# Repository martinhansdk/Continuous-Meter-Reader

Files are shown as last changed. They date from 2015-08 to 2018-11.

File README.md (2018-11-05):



# Continuous Meter Reader

A little gadget that sits on your water or electricity meter and
monitors it continuously.  The collected reading are presented on a
mobile web page so that you can practice saving ressources by
answering questions like "How much water do I use when I take a
shower?".

Currently Sensus water meters are supported. They look like this:

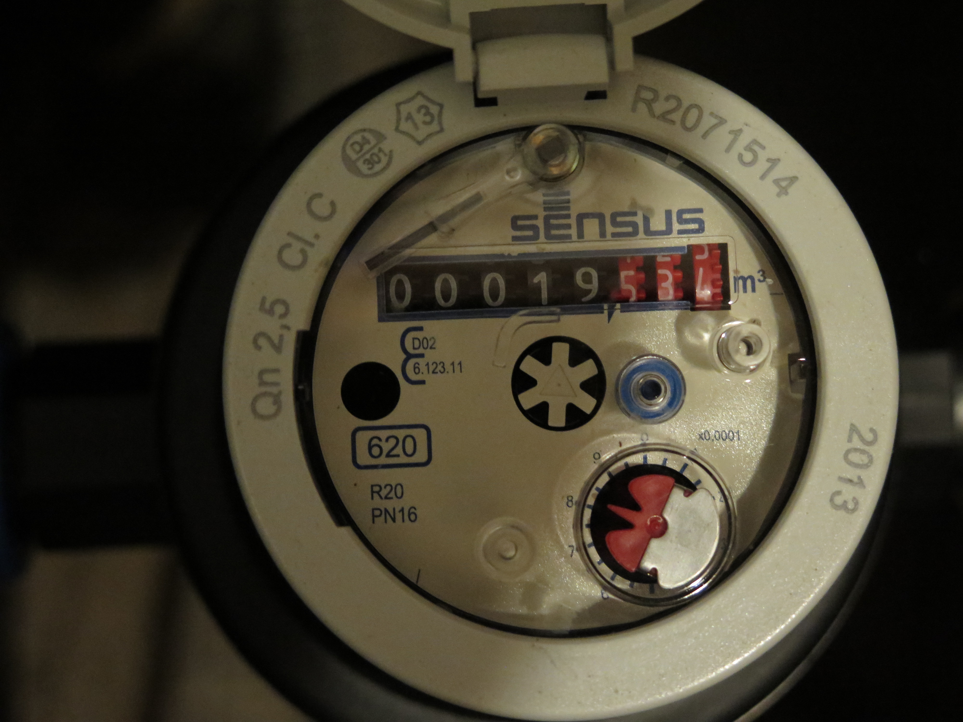
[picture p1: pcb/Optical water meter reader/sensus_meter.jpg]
Sensus water meter


I have designed two versions of a PCB which fits on top of the water
meter which uses [GP2S700HCP reflective
photointerrupter](http://www.sharp-world.com/products/device/lineup/data/pdf/datasheet/gp2s700hcp_e.pdf)
sensors to read the turning of the half shiny half red disc. The disc
makes one turn per liter. The PCB has six optical sensors, so it can
sense quantities around 1/12 of a liter. The reflective part of the
disc is not exactly a half circle, so the exact 12 quantities measured
are different from each other. An automatic calibration method is
provided which determines how much each quantity is. You can print a
[PDF rendering of the PCB layout](pcb/Optical%20water%20meter%20reader/optical%20meter%20reader%20board.pdf), make 5mm holes for the
steering pins plus a small hole for the middle of the sensor circle in
your printout and see if it will fit on your meter. When attached to
your meter the small hole should be right above the center of the
disc.

Photo of the PCB

* The top row shows the version of the PCB designed to run on two 1.5V batteries and transmit the readings wirelessly.
  * [Eagle schematics](pcb/Optical%20water%20meter%20reader/optical%20meter%20reader%20v3.sch) / [PDF schematics](pcb/Optical%20water%20meter%20reader/optical%20meter%20reader%20v3%20battery%20assembly.pdf)
  * [Eagle board file](pcb/Optical%20water%20meter%20reader/optical%20meter%20reader%20v3.brd)
  * [Gerber files](pcb/Optical%20water%20meter%20reader/optical%20meter%20reader%20v3%20-%20gerber.zip)
  * [Bill of materials](pcb/Optical%20water%20meter%20reader/optical%20meter%20reader%20v3%20battery%20assembly%20BOM.txt)
  * [Firmware](src/Continuous-Meter-Reader/Continuous-Meter-Reader.ino)
* The bottom row shows the version of the PCB designed to be connected directly to a PC using a USB cable. In the configuration shown here it operates as the radio receiver that receives the readings transmitted from other units.
  * [Eagle schematics](pcb/Optical%20water%20meter%20reader/optical%20meter%20reader.sch) / [PDF schematics](pcb/Optical%20water%20meter%20reader/optical%20meter%20reader.pdf)
  * [Eagle board file](pcb/Optical%20water%20meter%20reader/optical%20meter%20reader.brd)
  * [Gerber files](pcb/Optical%20water%20meter%20reader/optical%20meter%20reader%20gerber.zip)
  * [Firmware](src/RadioStation/RadioStation.ino)

The ambition is that the same or a similar PCB will be able to read
the turning weel on an old style electricity meter. The PCB was
designed in [Eagle pcb](http://www.cadsoftusa.com/).

The USB version uses an [Arduino
Nano](https://www.arduino.cc/en/Main/ArduinoBoardNano) as the CPU
module and [NRF24L01+ Wireless Transceiver
Module](http://www.icstation.com/1pcs-nrf24l0124ghz-wireless-transceiver-module-arduino-p-1388.html)
for wireless connectivity. The battery powered module has the
microcontroller directly on the PCB and uses the same wireless transceiver.

The server application runs on a PC written in
[Go](https://golang.org/) and stores the measurements in a
[PostgreSQL](http://www.postgresql.org) database. The server application
exposes a REST API, a [socket.io](http://socket.io/) service for real
time updates and also serves a web application written in
[React](http://facebook.github.io/react/).

The communication protocol between the embedded code and the server is
based on [Google's protocol
buffers](https://developers.google.com/protocol-buffers/) with the
Arduino implementation generated by
[Nanopb](http://koti.kapsi.fi/jpa/nanopb/). The protocol definition
file is [MeterReader.proto](MeterReader.proto).

## Software build instructions

All build instructions assume Ubuntu 15.04 or later.

### Install prerequisites

    sudo apt-get install make clang protobuf-compiler arduino postgresql-9.4 git
    wget https://godeb.s3.amazonaws.com/godeb-amd64.tar.gz
    tar xzf godeb-amd64.tar.gz
    ./godeb install

### Getting the code

The project uses git submodules, so you have to use a recursive clone to get everything:

    git clone --recursive https://github.com/martinhansdk/Continuous-Meter-Reader

### Uploading the embedded code to the MCU on the battery powered meter reader node

Using an AVR ISP programmer (for instance an Arduino with the
ArduinoISP sketch loaded), attach it to the ISP header on the meter
reader board. In the Arduino IDE select the appropriate programmer
type.  Choose the board type to be "Arduino Pro or Pro Mini (3.3V, 8
MHz) w/ ATmega328". Then run "Tools > Burn bootloader".

Once this has completed correctly, the brown out detection must be
cleared in the AVR in order to allow operating the AVR at 2.5V. Do
this by running:

    avrdude -patmega328p -cstk500v1 -P /dev/ttyUSB? -b19200 -U efuse:w:0xff:m

Now disconnect the ISP and connect a 3.3V FTDI USB to serial adapter to
JP2. The run

    cd src/Continuous-Meter-Reader
    make upload

### Uploading the embedded code to the Arduino on the receiver station
    
Attach the Arduino for the server receiver station and run

    cd src/RadioStation
    make upload
    
### Building the server and node configuration tool

    cd go
    export GOPATH=$PWD
    go get -d
    go build MeterServer.go 
    go build ConfigNode.go 
    go build SampleSender.go 

### Setup the PostgreSQL database

Drop step 1 if you already have a database running

1. change postgres default password:
   su - postgres
   psql
   \password postgres
   <enter new password>
2. Create the 'meter' user:
   CREATE USER meter;
3. Set user password:
   \password meter;
   <use password: meter2>
3. Create the database:
   CREATE DATABASE meter;
4. Grant priviledges to meter on database:
   GRANT ALL PRIVILEGES ON DATABASE meter TO meter;
5. Grant priviledges to meter on the database tables:
   GRANT ALL PRIVILEGES ON TABLE meters TO meter;
   GRANT ALL PRIVILEGES ON TABLE measurements TO meter;
6. Create the database fields by executing the commands in database.sql
7. Insert the first meter into the meter table:
   INSERT INTO meters(
               id, name, unit, current_series, last_count, scale)
       VALUES (1, 'Mock meter', "L", "0", "0", 1e-3),
              (10,  "Water", "L", "0", "0", 1e-3);
   
### Configuring the Arduino for a meter

Each node has an id which is an integer between 1 and 127. We need to
set this id and also choose the wireless or serial (USB)
protocol. Configuration can only happen over USB.

To configure an Arduino that is attached to /dev/ttyUSB0 run something like the following:

    go/ConfigNode -serial=/dev/ttyUSB0 -wirelessproto -id=10 -uncalibrate

### Calibrating a meter sensor

The calibration procedure is as follows:

1. Attach the PCB to the water meter
2. Connect the Arduino to the PC using a USB cable
3. Turn on a tap so that a constant flow is running. Make sure this is the only place water is consumed in the house while the calibration is running
4. Run the command `go/ConfigNode -serial=/dev/ttyUSB0 -calibrate`
5. The command will exit when calibration is complete

### Running the Server

Once the database is set up, and the MeterServer built, it can be run:

   cd go
   ./MeterServer

Contact the server using http://localhost:2111/static

## Running the mock meter (offline mode)

Running tests with out having to flush a lot of water makes sense, so use the

   cd go
   ./SampleSender

for this purpose.

If everything is ok, the example output should look something like this:

    2015/11/10 22:25:00 Waiting for current settings
    2015/11/10 22:25:00 Connection established
    2015/11/10 22:25:00 Waiting for data
    2015/11/10 22:25:02 len= 14
    2015/11/10 22:25:02 n=14
    2015/11/10 22:25:02 NOTE : Received 'Rebooted'
    2015/11/10 22:25:02 Waiting for data
    2015/11/10 22:25:02 len= 24
    2015/11/10 22:25:02 n=24
    2015/11/10 22:25:02 Waiting for data
    2015/11/10 22:25:02 Got current settings
    {"meterId":2,"seriesId":73,"communicationChannel":1,"risingEdgeAmounts":[0,1,2,3,4,5],"fallingEdgeAmounts":[0,1,2,3,4,5]}
    2015/11/10 22:25:02 id=4294967295
    2015/11/10 22:25:57 len= 27
    2015/11/10 22:25:57 n=27
    2015/11/10 22:25:57 Waiting for data
    {"meterId":2,"seriesId":73,"communicationChannel":1,"risingEdgeAmounts":[127,93,117,149,169,153],"fallingEdgeAmounts":[33,15,17,38,41,48]}

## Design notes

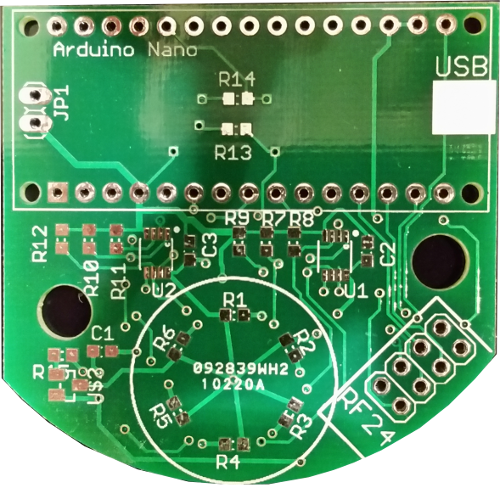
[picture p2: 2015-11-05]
pcb/Optical water meter reader/optical meter reader pcb photo.png

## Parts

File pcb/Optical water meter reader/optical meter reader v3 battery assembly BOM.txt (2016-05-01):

Partlist exported from C:/Users/Hans/Documents/eagle/Optical water meter reader/optical meter reader v3.sch at 2016-04-21 11:47 AM

Part  Value          Device                    Package       Description                                                                                                                                                                                                        
C1    100n           C-USC0603                 C0603         CAPACITOR, American symbol                                                                                                                                                                                         
C2    100n           C-USC0603                 C0603         CAPACITOR, American symbol                                                                                                                                                                                         
C3    100n           C-USC0603                 C0603         CAPACITOR, American symbol                                                                                                                                                                                         
C4    100n           C-USC0603                 C0603         CAPACITOR, American symbol                                                                                                                                                                                         
C5    100n           C-USC0603                 C0603         CAPACITOR, American symbol                                                                                                                                                                                         
C6    100n           C-USC0603                 C0603         CAPACITOR, American symbol                                                                                                                                                                                         
C7    100n           C-USC0603                 C0603         CAPACITOR, American symbol                                                                                                                                                                                         
C8    10u            C-EUC0603                 C0603         CAPACITOR, European symbol                                                                                                                                                                                         
C9    10u            C-USC0603                 C0603         CAPACITOR, American symbol                                                                                                                                                                                         
C10   10u            C-USC0603                 C0603         CAPACITOR, American symbol                                                                                                                                                                                         
JP2   FTDI Basic     ARDUINO_SERIAL_PROGRAMPTH 1X06                                                                                                                                                                                                                             
JP3   RF24           PINHD-2X4                 2X04          PIN HEADER                                                                                                                                                                                                         
JP5   LUM1613-14     LUM1613-14                1613-14       Lumberg 1613 12 DC power connector                                                                                                                                                                                 
JP6   2X4SMD         2X4SMD                    2X4_SMD                                                                                                                                                                                                                          
LED1  Green          LED                       0603-LED-ALT1 LEDs                                                                                                                                                                                                               
LOGO1 OSHW-LOGOL     OSHW-LOGOL                OSHW-LOGO-L   Open Source Hardware Logo This logo indicates the piece of hardware it is found on incorporates a OSHW license and/or adheres to the definition of open source hardware found here: http://freedomdefined.org/OSHW 
LOGO2 OSHW-LOGOL     OSHW-LOGOL                OSHW-LOGO-L   Open Source Hardware Logo This logo indicates the piece of hardware it is found on incorporates a OSHW license and/or adheres to the definition of open source hardware found here: http://freedomdefined.org/OSHW 
Q1    8MHz           CSTCE                     CSTCE         Murata CSTCE                                                                                                                                                                                                       
R1    10K            R-US_R0603                R0603         RESISTOR, American symbol                                                                                                                                                                                          
R2    1k             R-US_R0603                R0603         RESISTOR, American symbol                                                                                                                                                                                          
R3    1k             R-US_R0603                R0603         RESISTOR, American symbol                                                                                                                                                                                          
R4    750            R-US_R0603                R0603         RESISTOR, American symbol                                                                                                                                                                                          
R5    1k             R-US_R0603                R0603         RESISTOR, American symbol                                                                                                                                                                                          
R8    1k             R-US_R0603                R0603         RESISTOR, American symbol                                                                                                                                                                                          
R12   3k             R-US_R0603                R0603         RESISTOR, American symbol                                                                                                                                                                                          
R13   3k             R-US_R0603                R0603         RESISTOR, American symbol                                                                                                                                                                                          
R14   3k             R-US_R0603                R0603         RESISTOR, American symbol                                                                                                                                                                                          
R15   3k             R-US_R0603                R0603         RESISTOR, American symbol                                                                                                                                                                                          
R16   3k             R-US_R0603                R0603         RESISTOR, American symbol                                                                                                                                                                                          
R17   3k             R-US_R0603                R0603         RESISTOR, American symbol                                                                                                                                                                                          
R19   82             R-US_R0603                R0603         RESISTOR, American symbol                                                                                                                                                                                          
R20   82             R-US_R0603                R0603         RESISTOR, American symbol                                                                                                                                                                                          
R21   82             R-US_R0603                R0603         RESISTOR, American symbol                                                                                                                                                                                          
R22   82             R-US_R0603                R0603         RESISTOR, American symbol                                                                                                                                                                                          
R23   82             R-US_R0603                R0603         RESISTOR, American symbol                                                                                                                                                                                          
R24   82             R-US_R0603                R0603         RESISTOR, American symbol                                                                                                                                                                                          
R26   1M             R-US_R0603                R0603         RESISTOR, American symbol                                                                                                                                                                                          
R27   2M             R-US_R0603                R0603         RESISTOR, American symbol                                                                                                                                                                                          
R32   0              R-US_R0603                R0603         RESISTOR, American symbol                                                                                                                                                                                          
S0    GP2S700HCP     GP2S700HCP                SMD                                                                                                                                                                                                                              
S1    GP2S700HCP     GP2S700HCP                SMD                                                                                                                                                                                                                              
S2    GP2S700HCP     GP2S700HCP                SMD                                                                                                                                                                                                                              
S3    GP2S700HCP     GP2S700HCP                SMD                                                                                                                                                                                                                              
S4    GP2S700HCP     GP2S700HCP                SMD                                                                                                                                                                                                                              
S5    GP2S700HCP     GP2S700HCP                SMD                                                                                                                                                                                                                              
T1    IRML6401       IRML6401                  SOT23                                                                                                                                                                                                                            
T2    IRML6401       IRML6401                  SOT23                                                                                                                                                                                                                            
U1    LM8364         LM8364                    SOT23-DBV     LM8364 Micropower Undervoltage Sensing Circuits                                                                                                                                                                    
U2    ATMEGA328P     ATMEGA168                 TQFP32-08                                                                                                                                                                                                                        
U3    SN74LVC3G17DCT SN743G17DCT               SSOP08                                                                                                                                                                                                                           
U4    SN74LVC3G17DCT SN743G17DCT               SSOP08                                                                                                                                                                                                                           
U5    MCP1700 2V5    MCP1700                   SOT23

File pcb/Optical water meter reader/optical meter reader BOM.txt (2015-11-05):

Partlist exported from C:/Users/Hans/Documents/eagle/Optical water meter reader/optical meter reader.sch at 28-Aug-15 11:16 PM

Part Value       Device      Package Description                
C1   2.2u        C-EUC0603   C0603   CAPACITOR, European symbol 
C2   100n        C-USC0603   C0603   CAPACITOR, American symbol 
C3   100n        C-USC0603   C0603   CAPACITOR, American symbol 
JP1              PINHD-1X2   1X02    PIN HEADER                 
JP2  RF24        PINHD-2X4   2X04    PIN HEADER                 
R1   220         R-US_R0603  R0603   RESISTOR, American symbol  
R2   220         R-US_R0603  R0603   RESISTOR, American symbol  
R3   220         R-US_R0603  R0603   RESISTOR, American symbol  
R4   220         R-US_R0603  R0603   RESISTOR, American symbol  
R5   220         R-US_R0603  R0603   RESISTOR, American symbol  
R6   220         R-US_R0603  R0603   RESISTOR, American symbol  
R7   10k         R-US_R0603  R0603   RESISTOR, American symbol  
R8   10k         R-US_R0603  R0603   RESISTOR, American symbol  
R9   10k         R-US_R0603  R0603   RESISTOR, American symbol  
R10  10k         R-US_R0603  R0603   RESISTOR, American symbol  
R11  10k         R-US_R0603  R0603   RESISTOR, American symbol  
R12  10k         R-US_R0603  R0603   RESISTOR, American symbol  
R13  220         R-US_R0603  R0603   RESISTOR, American symbol  
R14  10k         R-US_R0603  R0603   RESISTOR, American symbol  
R15  1k          R-US_R0603  R0603   RESISTOR, American symbol  
S0   GP2S700HCP  GP2S700HCP  SMD                                
S1   GP2S700HCP  GP2S700HCP  SMD                                
S2   GP2S700HCP  GP2S700HCP  SMD                                
S3   GP2S700HCP  GP2S700HCP  SMD                                
S4   GP2S700HCP  GP2S700HCP  SMD                                
S5   GP2S700HCP  GP2S700HCP  SMD                                
S6   GP2S700HCP  GP2S700HCP  SMD                                
U$1  ARDUINONANO ARDUINONANO PDIP-32                            
U$2  IRLML6401   IRLML6401   SOT23                              
U1   SN743G17DCT SN743G17DCT SSOP08                             
U2   SN743G17DCT SN743G17DCT SSOP08

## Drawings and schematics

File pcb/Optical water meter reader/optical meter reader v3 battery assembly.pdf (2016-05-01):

# R18 R¹¹

3

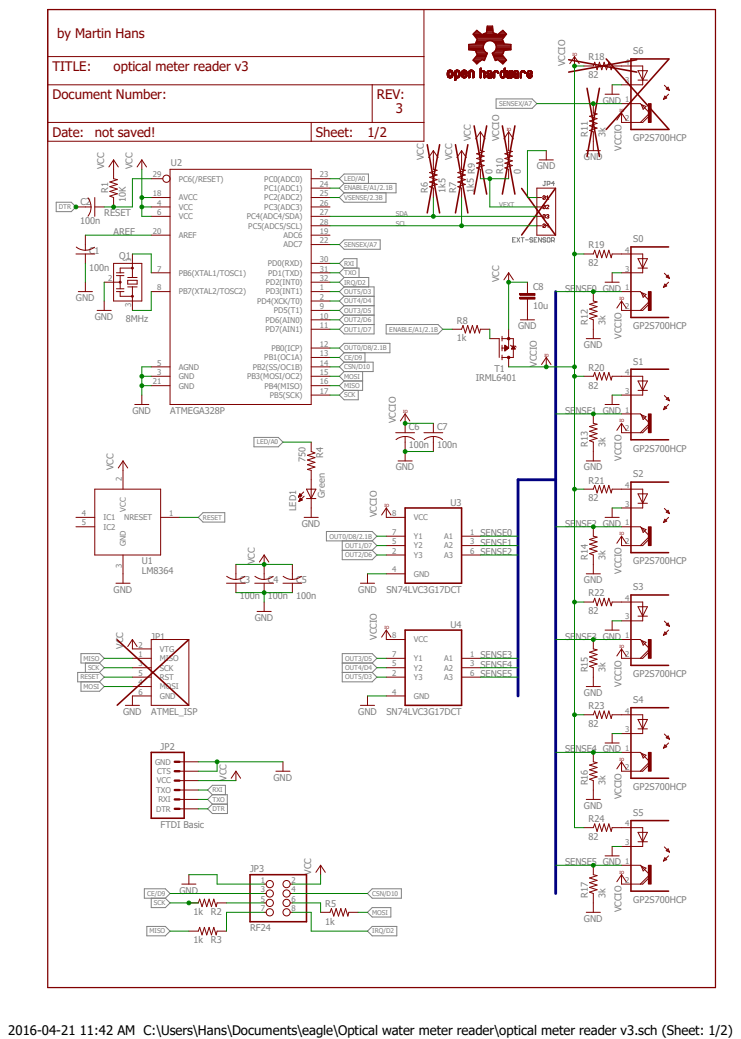
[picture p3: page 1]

AREF | | VCC 6
AREF 20 | SCL

2016-04-21 11:42 AM C:\Users\Hans\Documents\eagle\Optical water meter reader\optical meter reader v3.sch (Sheet: 1/2)

3

## by Martin Hans

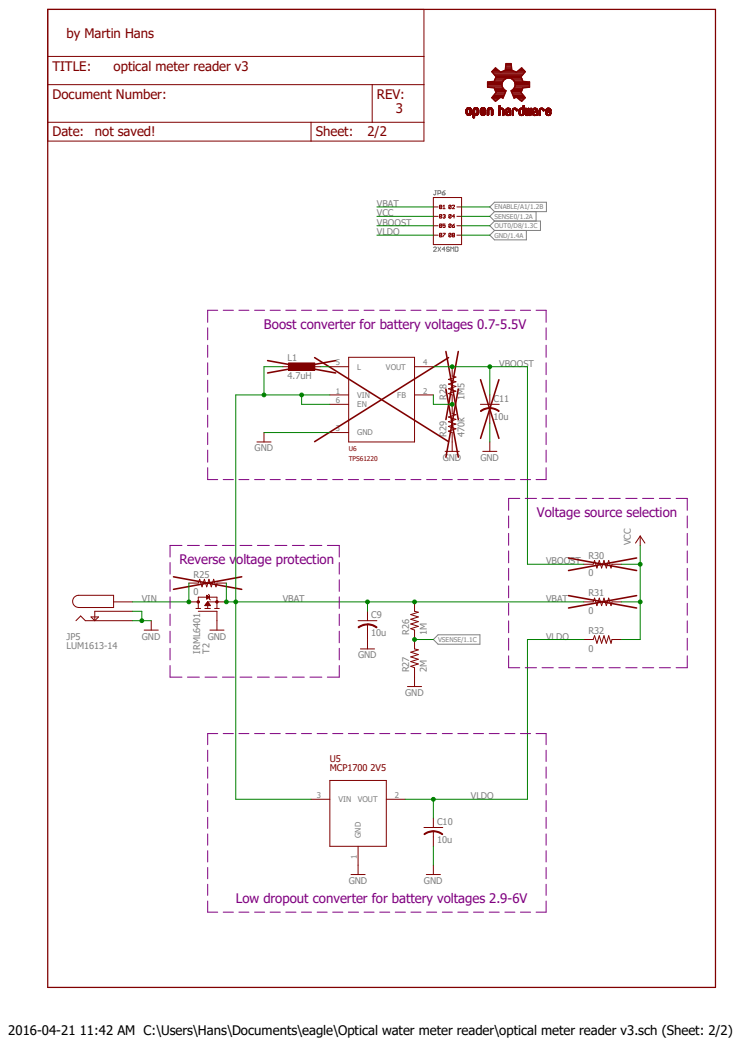
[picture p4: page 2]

Low dropout converter for battery voltages 2.9-6V

2016-04-21 11:42 AM C:\Users\Hans\Documents\eagle\Optical water meter reader\optical meter reader v3.sch (Sheet: 2/2)

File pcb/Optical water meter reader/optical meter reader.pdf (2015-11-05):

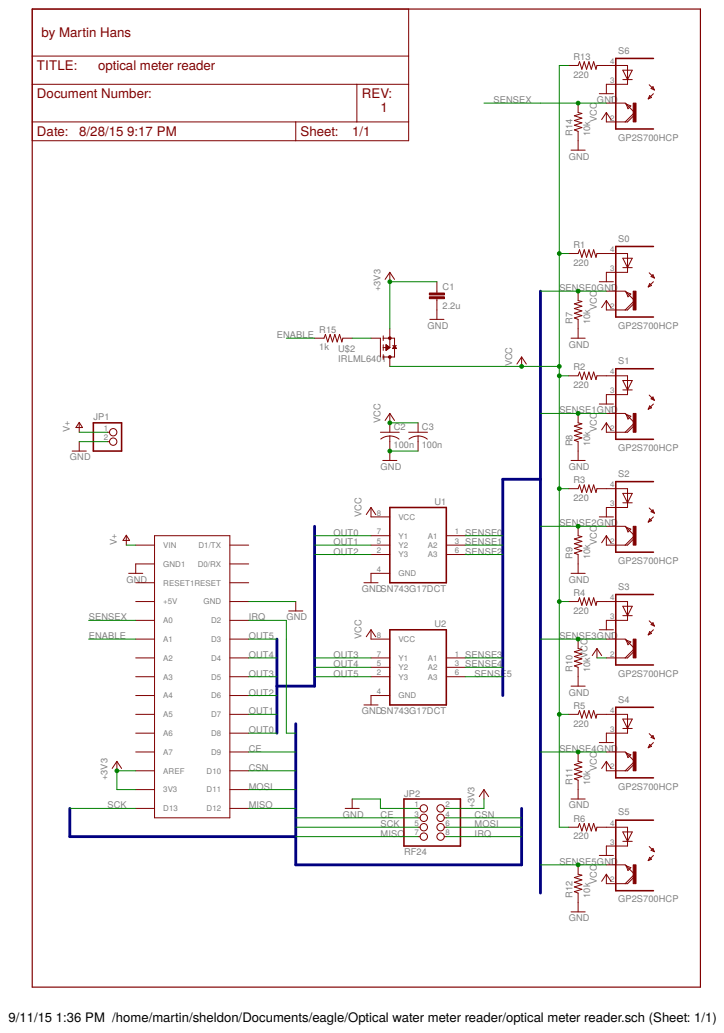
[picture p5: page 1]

D1/TX D0/RX RESET GND

9/11/15 1:36 PM /home/martin/sheldon/Documents/eagle/Optical water meter reader/optical meter reader.sch (Sheet: 1/1)

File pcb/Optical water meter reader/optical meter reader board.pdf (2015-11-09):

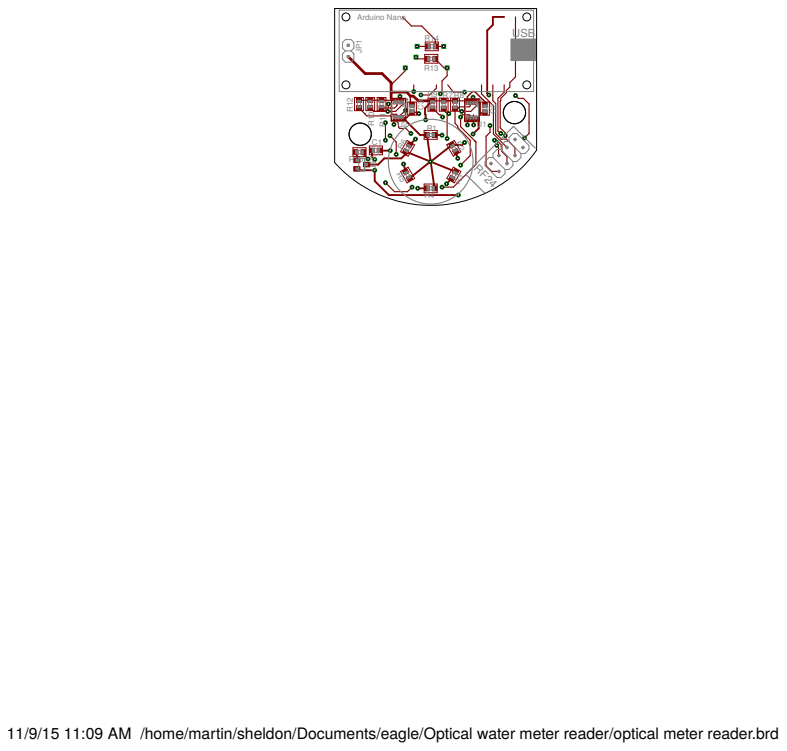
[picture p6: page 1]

11/9/15 11:09 AM /home/martin/sheldon/Documents/eagle/Optical water meter reader/optical meter reader.brd

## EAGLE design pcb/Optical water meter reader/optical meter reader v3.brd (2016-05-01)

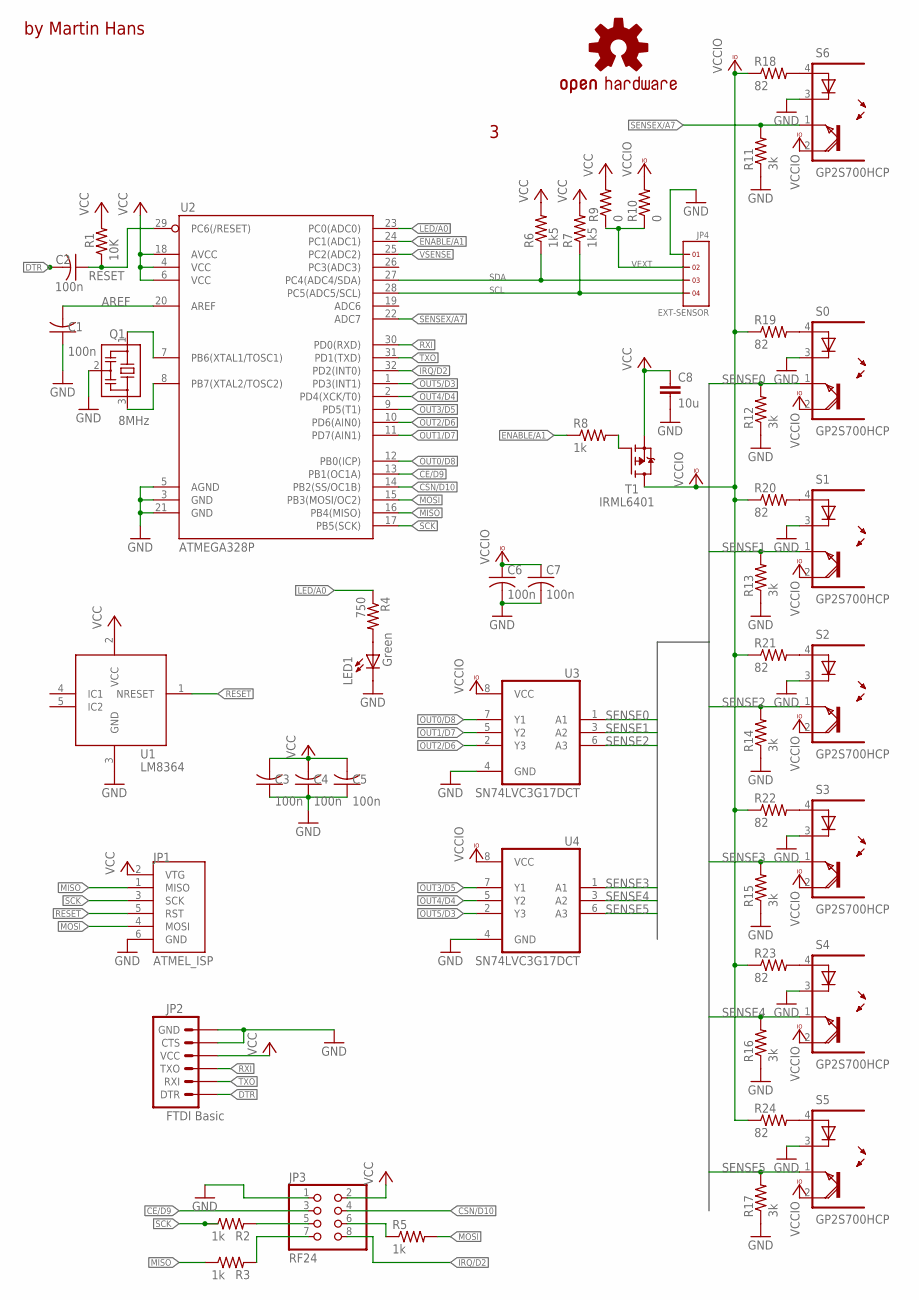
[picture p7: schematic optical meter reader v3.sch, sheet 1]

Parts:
C1, C2, C3, C4, C5, C6, C7: 100n; C0603
C8: 10u; C0603
JP1: ATMEL_ISP; 2X03
JP2: FTDI Basic; 1X06
JP3: RF24; 2X04
JP4: EXT-SENSOR; 1X4
LED1: Green; 0603-LED-ALT1
LOGO1: OSHW-LOGOL; OSHW-LOGO-L
Q1: 8MHz; CSTCE
R1: 10K; R0603
R2, R3, R5, R8: 1k; R0603
R4: 750; R0603
R6, R7: 1k5; R0603
R9, R10: 0; R0603
R11, R12, R13, R14, R15, R16, R17: 3k; R0603
R18, R19, R20, R21, R22, R23, R24: 82; R0603
S0, S1, S2, S3, S4, S5, S6: GP2S700HCP; SMD
T1: IRML6401; SOT23
U1: LM8364; SOT23-DBV
U2: ATMEGA328P; TQFP32-08
U3, U4: SN74LVC3G17DCT; SSOP08

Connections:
AREF: C1.2, U2.20 (AREF)
CE/D9: JP3.3, U2.13 (PB1(OC1A))
CSN/D10: JP3.4, U2.14 (PB2(SS/OC1B))
DTR: C2.2, JP2.1 (DTR)
ENABLE/A1: R8.1, U2.24 (PC1(ADC1)); also elsewhere on the board
GND: C1.1, C3.1, C4.1, C5.1, C6.2, C7.2, C8.2, JP1.6 (GND), JP2.5 (CTS), JP2.6 (GND), JP3.1, JP4.1, LED1.C, Q1.2, R11.1, R12.1, R13.1, R14.1, R15.1, R16.1, R17.1, S0.3 (C), S1.3 (C), S2.3 (C), S3.3 (C), S4.3 (C), S5.3 (C), S6.3 (C), U1.3 (GND), U2.3 (GND), U2.5 (AGND), U2.21 (GND), U3.4 (GND), U4.4 (GND); also elsewhere on the board
IRQ/D2: JP3.8, U2.32 (PD2(INT0))
LED/A0: R4.1, U2.23 (PC0(ADC0))
MISO: JP1.1 (MISO), R3.1, U2.16 (PB4(MISO))
MOSI: JP1.4 (MOSI), R5.2, U2.15 (PB3(MOSI/OC2))
unnamed: R19.2, S0.4 (A)
unnamed: R20.2, S1.4 (A)
unnamed: R21.2, S2.4 (A)
unnamed: R22.2, S3.4 (A)
unnamed: R23.2, S4.4 (A)
unnamed: R18.2, S6.4 (A)
unnamed: R8.2, T1.1 (G)
unnamed: R24.2, S5.4 (A)
unnamed: LED1.A, R4.2
unnamed: Q1.3, U2.8 (PB7(XTAL2/TOSC2))
unnamed: Q1.1, U2.7 (PB6(XTAL1/TOSC1))
unnamed: JP3.6, R5.1
unnamed: JP3.7, R3.2
unnamed: JP3.5, R2.2
OUT0/D8: U2.12 (PB0(ICP)), U3.7 (Y1); also elsewhere on the board
OUT1/D7: U2.11 (PD7(AIN1)), U3.5 (Y2)
OUT2/D6: U2.10 (PD6(AIN0)), U3.2 (Y3)
OUT3/D5: U2.9 (PD5(T1)), U4.7 (Y1)
OUT4/D4: U2.2 (PD4(XCK/T0)), U4.5 (Y2)
OUT5/D3: U2.1 (PD3(INT1)), U4.2 (Y3)
RESET: C2.1, JP1.5 (RST), R1.1, U1.1 (NRESET), U2.29 (PC6(/RESET))
RXI: JP2.3 (TXO), U2.30 (PD0(RXD))
SCK: JP1.3 (SCK), R2.1, U2.17 (PB5(SCK))
SCL: JP4.4, R7.1, U2.28 (PC5(ADC5/SCL))
SDA: JP4.3, R6.1, U2.27 (PC4(ADC4/SDA))
SENSE0: R12.2, S0.1 (EMI), U3.1 (A1); also elsewhere on the board
SENSE1: R13.2, S1.1 (EMI), U3.3 (A2)
SENSE2: R14.2, S2.1 (EMI), U3.6 (A3)
SENSE3: R15.2, S3.1 (EMI), U4.1 (A1)
SENSE4: R16.2, S4.1 (EMI), U4.3 (A2)
SENSE5: R17.2, S5.1 (EMI), U4.6 (A3)
SENSEX/A7: R11.2, S6.1 (EMI), U2.22 (ADC7)
TXO: JP2.2 (RXI), U2.31 (PD1(TXD))
VCC: C3.2, C4.2, C5.2, C8.1, JP1.2 (VTG), JP2.4 (VCC), JP3.2, R1.2, R6.2, R7.2, R9.2, T1.2 (S), U1.2 (VCC), U2.4 (VCC), U2.6 (VCC), U2.18 (AVCC); also elsewhere on the board
VCCIO: C6.1, C7.1, R10.2, R18.1, R19.1, R20.1, R21.1, R22.1, R23.1, R24.1, S0.2 (COL), S1.2 (COL), S2.2 (COL), S3.2 (COL), S4.2 (COL), S5.2 (COL), S6.2 (COL), T1.3 (D), U3.8 (VCC), U4.8 (VCC)
VEXT: JP4.2, R9.1, R10.1
VSENSE: U2.25 (PC2(ADC2)); also elsewhere on the board

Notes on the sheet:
by Martin Hans

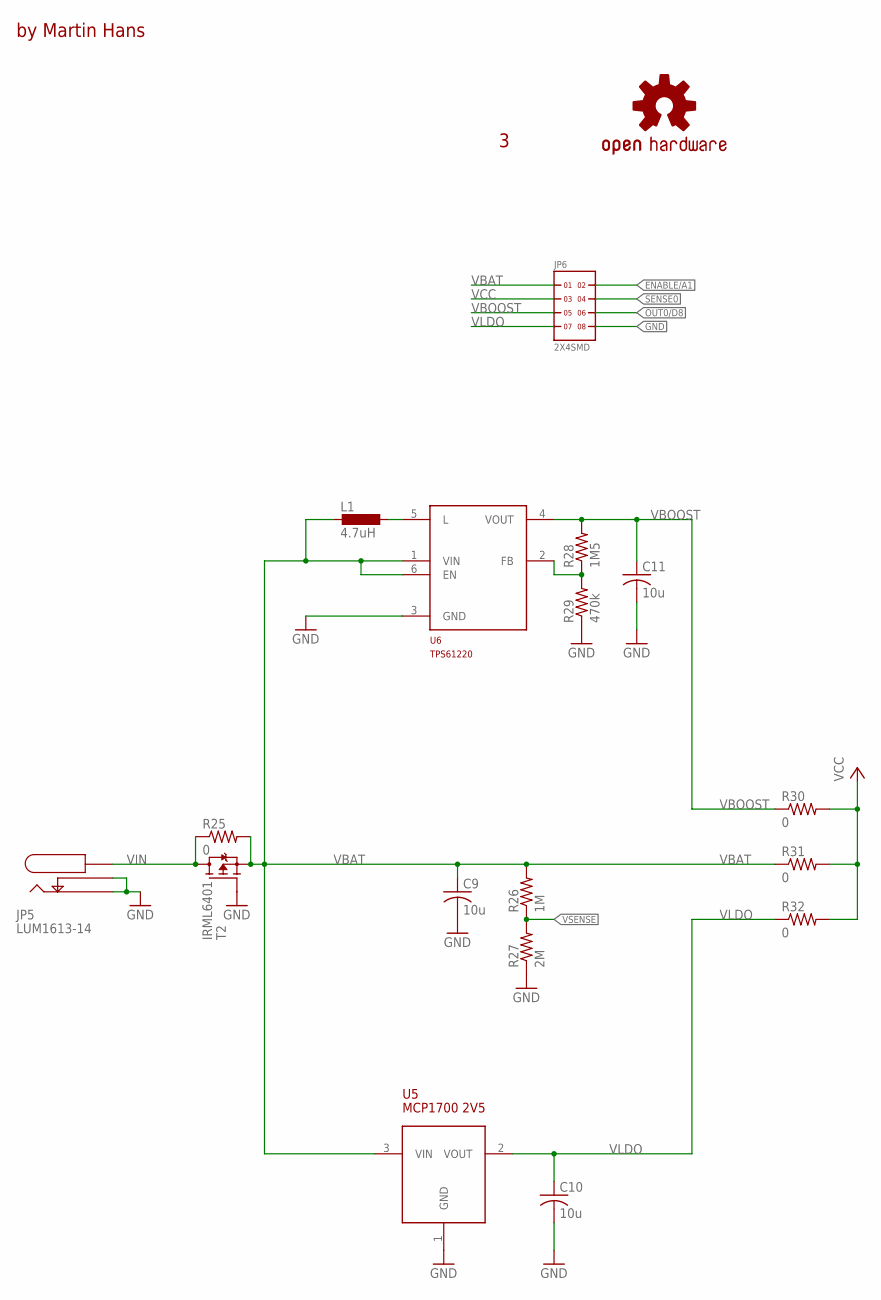
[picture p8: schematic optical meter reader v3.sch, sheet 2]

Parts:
C9, C10, C11: 10u; C0603
JP5: LUM1613-14; 1613-14
JP6: 2X4SMD; 2X4_SMD
L1: 4.7uH; EPL3015
LOGO2: OSHW-LOGOL; OSHW-LOGO-L
R25, R30, R31, R32: 0; R0603
R26: 1M; R0603
R27: 2M; R0603
R28: 1M5; R0603
R29: 470k; R0603
T2: IRML6401; SOT23
U5: MCP1700 2V5; SOT23
U6: TPS61220; DCK-R_PDSO_G6

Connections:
ENABLE/A1: JP6.2; also elsewhere on the board
FB: R28.1, R29.2, U6.2 (FB)
GND: C9.2, C10.2, C11.2, JP5.1 (SHIELD), JP5.2 (CONNECT), JP6.8, R27.1, R29.1, T2.1 (G), U5.1 (GND), U6.3 (GND); also elsewhere on the board
L: L1.P$2 (2), U6.5 (L)
OUT0/D8: JP6.6; also elsewhere on the board
SENSE0: JP6.4; also elsewhere on the board
VBAT: C9.1, JP6.1, L1.P$1 (1), R25.2, R26.2, R31.1, T2.2 (S), U5.3 (VIN), U6.1 (VIN), U6.6 (EN)
VBOOST: C11.1, JP6.5, R28.2, R30.1, U6.4 (VOUT)
VCC: JP6.3, R30.2, R31.2, R32.2; also elsewhere on the board
VIN: JP5.3@1 (CENTER), JP5.3@2 (CENTER), R25.1, T2.3 (D)
VLDO: C10.1, JP6.7, R32.1, U5.2 (VOUT)
VSENSE: R26.1, R27.2; also elsewhere on the board

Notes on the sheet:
by Martin Hans

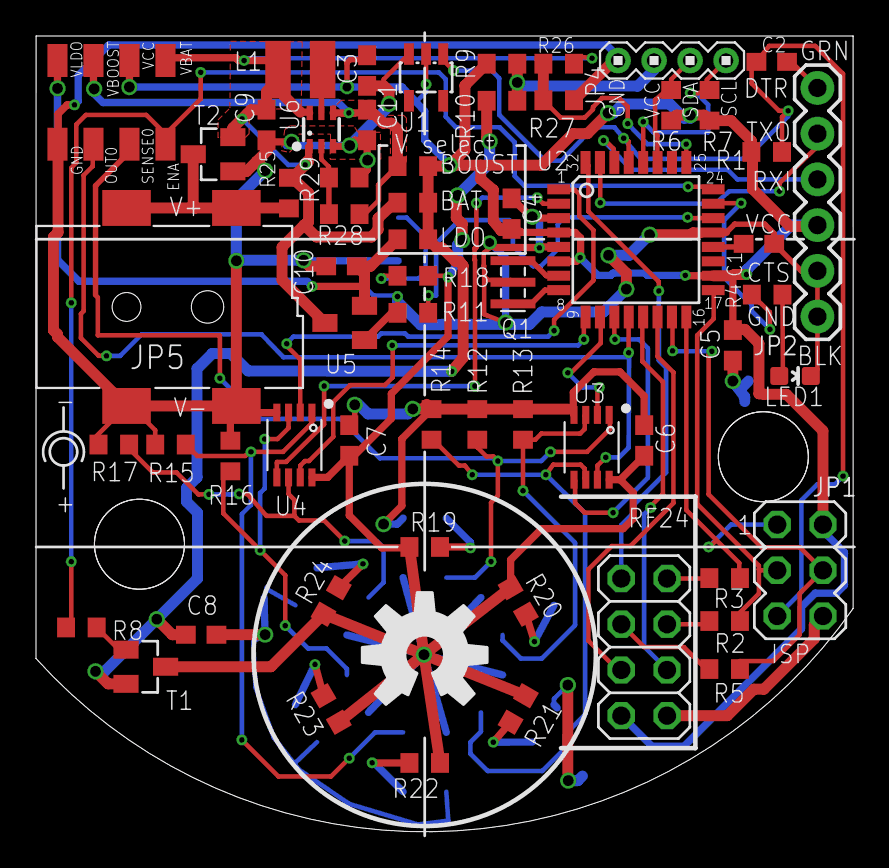
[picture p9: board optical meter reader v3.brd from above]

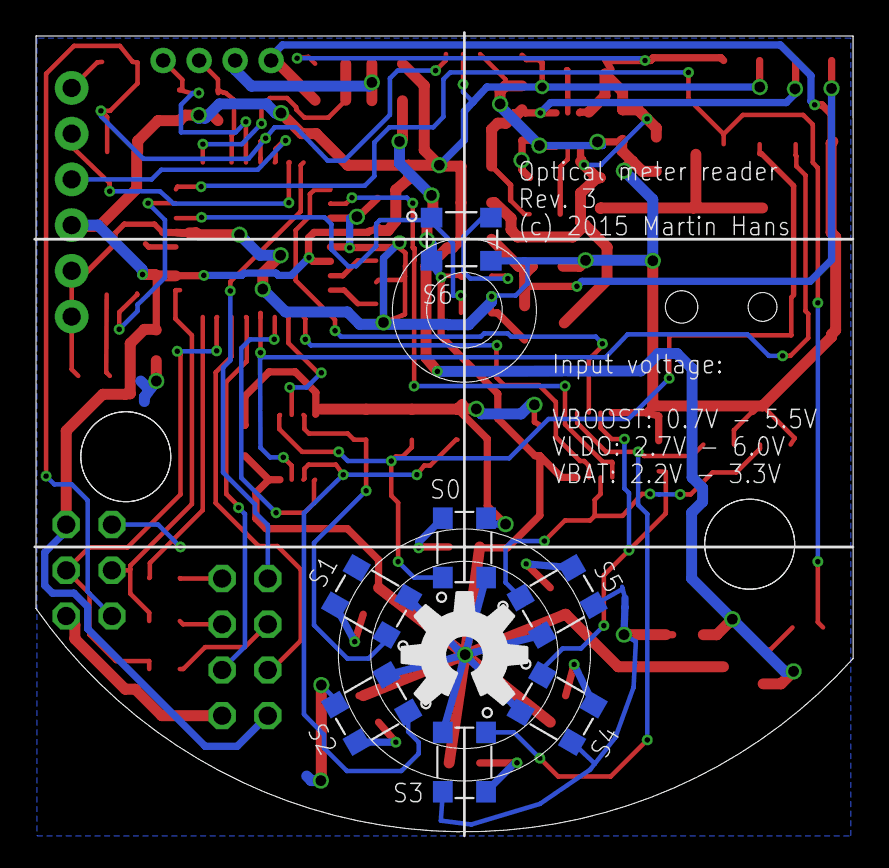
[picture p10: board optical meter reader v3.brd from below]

Board: 2 copper layers, 45.4 x 44.2 mm, 69 parts (8 on the bottom side), 53 nets.

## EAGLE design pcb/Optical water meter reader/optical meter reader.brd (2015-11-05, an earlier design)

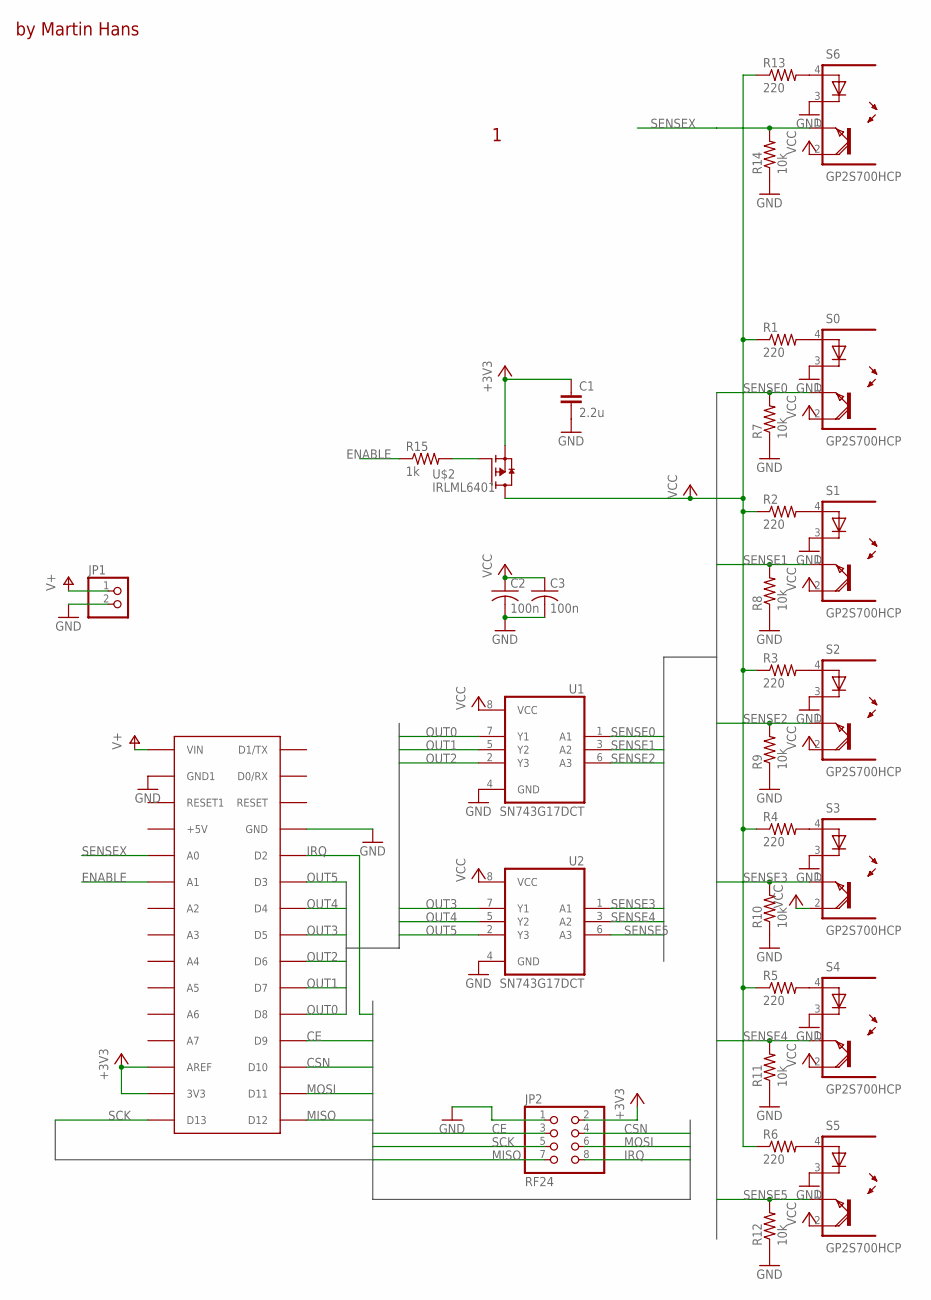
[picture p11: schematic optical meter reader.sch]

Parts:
C1: 2.2u; C0603
C2, C3: 100n; C0603
JP1: PINHD-1X2; 1X02
JP2: RF24; 2X04
R1, R2, R3, R4, R5, R6, R13: 220; R0603
R7, R8, R9, R10, R11, R12, R14: 10k; R0603
R15: 1k; R0603
S0, S1, S2, S3, S4, S5, S6: GP2S700HCP; SMD
U1, U2: SN743G17DCT; SSOP08
U$1: ARDUINONANO; PDIP-32
U$2: IRLML6401; SOT23

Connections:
+3V3: C1.1, JP2.2, U$1.3V3, U$1.AREF, U$2.2 (S)
CE: JP2.3, U$1.D9
CSN: JP2.4, U$1.D10
ENABLE: R15.1, U$1.A1
GND: C1.2, C2.2, C3.2, JP1.2, JP2.1, R7.1, R8.1, R9.1, R10.1, R11.1, R12.1, R14.1, S0.3 (C), S1.3 (C), S2.3 (C), S3.3 (C), S4.3 (C), S5.3 (C), S6.3 (C), U1.4 (GND), U2.4 (GND), U$1.GND, U$1.GND1
IRQ: JP2.8, U$1.D2
MISO: JP2.7, U$1.D12
MOSI: JP2.6, U$1.D11
unnamed: R1.2, S0.4 (A)
unnamed: R2.2, S1.4 (A)
unnamed: R3.2, S2.4 (A)
unnamed: R4.2, S3.4 (A)
unnamed: R5.2, S4.4 (A)
unnamed: R13.2, S6.4 (A)
unnamed: R15.2, U$2.1 (G)
unnamed: R6.2, S5.4 (A)
OUT0: U1.7 (Y1), U$1.D8
OUT1: U1.5 (Y2), U$1.D7
OUT2: U1.2 (Y3), U$1.D6
OUT3: U2.7 (Y1), U$1.D5
OUT4: U2.5 (Y2), U$1.D4
OUT5: U2.2 (Y3), U$1.D3
SCK: JP2.5, U$1.D13
SENSE0: R7.2, S0.1 (EMI), U1.1 (A1)
SENSE1: R8.2, S1.1 (EMI), U1.3 (A2)
SENSE2: R9.2, S2.1 (EMI), U1.6 (A3)
SENSE3: R10.2, S3.1 (EMI), U2.1 (A1)
SENSE4: R11.2, S4.1 (EMI), U2.3 (A2)
SENSE5: R12.2, S5.1 (EMI), U2.6 (A3)
SENSEX: R14.2, S6.1 (EMI), U$1.A0
V+: JP1.1, U$1.VIN
VCC: C2.1, C3.1, R1.1, R2.1, R3.1, R4.1, R5.1, R6.1, R13.1, S0.2 (COL), S1.2 (COL), S2.2 (COL), S3.2 (COL), S4.2 (COL), S5.2 (COL), S6.2 (COL), U1.8 (VCC), U2.8 (VCC), U$2.3 (D)

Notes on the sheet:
by Martin Hans

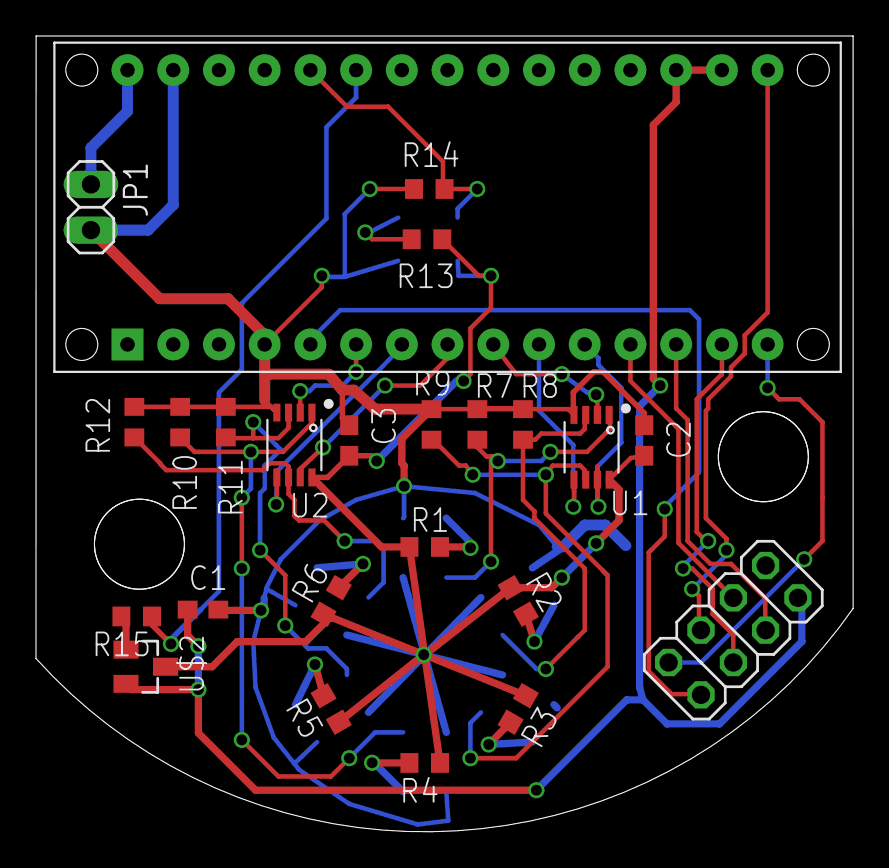
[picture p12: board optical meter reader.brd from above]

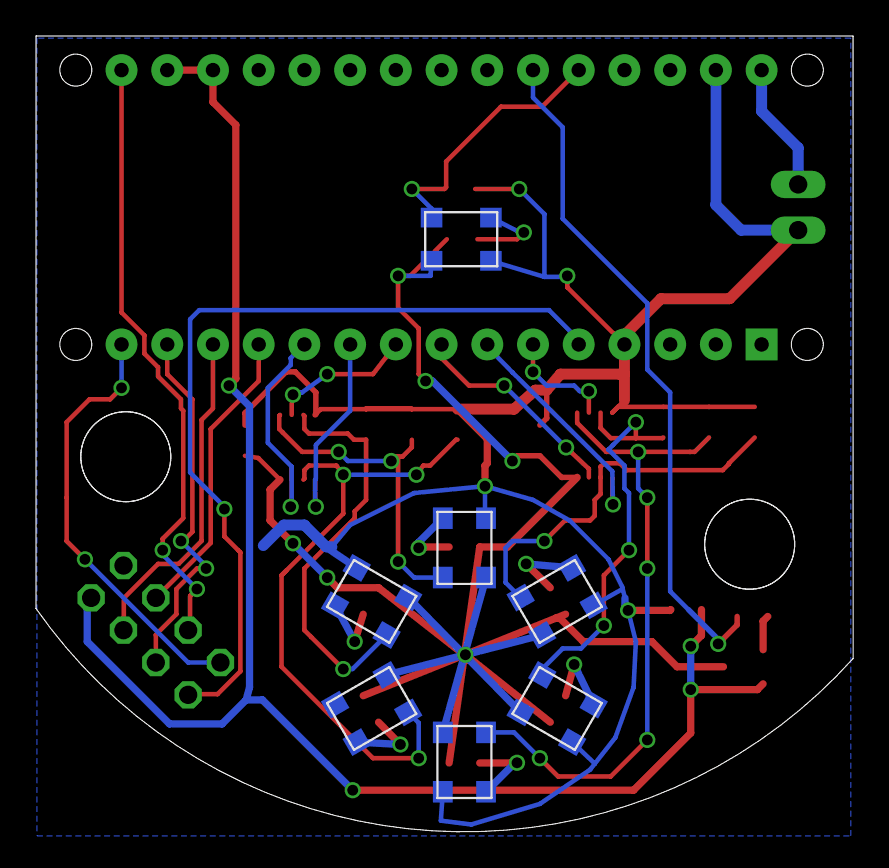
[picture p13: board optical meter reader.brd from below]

Board: 2 copper layers, 45.4 x 44.2 mm, 31 parts (7 on the bottom side), 32 nets.

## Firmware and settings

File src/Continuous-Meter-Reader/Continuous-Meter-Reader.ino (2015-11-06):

//-*-c++-*-
/* Meter reader */

#include <avr/power.h>
#include <avr/sleep.h>
#include <SPI.h>
#include "Histogram.h"
#include "Meter.h"
#include "Comparator.h"
#include "MeterReader_pb.h"
#include "OpticalSensor.h"
#include "settings.h"
#include "CommunicateSerial.h"
#include "CommunicateWireless.h"
#include "RadioMessageSender.h"
#include "crc32.h"

Settings<MeterReader_Settings> settings;

#define POWER_ENABLE_PIN A1

// the power enable pin is active low because it is connected to a P-MOS transistor
inline void power_leds_on() {
  digitalWrite(POWER_ENABLE_PIN, LOW);
}

inline void power_leds_off() {
  digitalWrite(POWER_ENABLE_PIN, HIGH);
}

// Hardware configuration: Set up nRF24L01 radio on SPI bus plus pins 9 & 10
RF24 radio(9, 10);
RadioMessageSender radioSender(radio);

const char* addresses[] = {"meterS", "meterR"};

Meter meter;
// digital sensors
OpticalSensor digitalSensors[] = {
  OpticalSensor(8),
  OpticalSensor(7),
  OpticalSensor(6),
  OpticalSensor(5),
  OpticalSensor(4),
  OpticalSensor(3)
};
OpticalSensorCalibrator calibrator(digitalSensors);

const int SAMPLE_FREQUENCY = 200; // Hz
const int SAMPLE_TIME = 1000 / SAMPLE_FREQUENCY; // ms
const int TICKS_BETWEEN_SEND = 200; // 1 second

bool calibrationMode, calibrationDone;
bool sendValueFlag;
unsigned int ticks; // must be big enough to hold TICKS_BETWEEN_SEND
Receiver<MeterReader_Message, MeterReader_Message_fields> serialinput(Serial);

uint64_t lastSentValue = UINT64_MAX;

void setup() {
  sendValueFlag = false;
  ticks = 0;
  calibrationMode = false;
  calibrationDone = false;

  pinMode(POWER_ENABLE_PIN, OUTPUT);
  power_leds_off();

  // pick the next series
  settings.load();
  settings.s.seriesId += 1;
  settings.save();

  // sanitize the number of digital sensors
  if(settings.s.fallingEdgeAmounts_count > 6) {
    settings.s.risingEdgeAmounts_count = 0;
  }

  settings.s.fallingEdgeAmounts_count = settings.s.risingEdgeAmounts_count;

  for(int i = 0 ; i < settings.s.risingEdgeAmounts_count ; i++) {
    digitalSensors[i].setRisingEdgeAmount(settings.s.risingEdgeAmounts[i]);
    digitalSensors[i].setFallingEdgeAmount(settings.s.fallingEdgeAmounts[i]);
  }

  Serial.begin(57600);

  // the serial port does not work reliably right after initializing
  // the port, this delay makes sure it's ready before we use it
  delay(500);
  sendLog(Serial, MeterReader_LogMessage_Type_NOTE, "Rebooted");
  sendSettings(Serial, settings.s);

  radio.begin();
  radio.setPALevel(RF24_PA_MAX);

  //myAddress = baseAddress + settings.s.meterId;
  radio.openWritingPipe((const uint8_t*)addresses[1]);
  radio.openReadingPipe(1, (const uint8_t*)addresses[0]);
  radio.enableDynamicPayloads();
  radio.stopListening();
  radio.powerDown();

  radioSender.begin(settings.s.meterId, settings.s.seriesId);

  // turn off unneeded hardware
  power_adc_disable();
  power_twi_disable();
  power_timer2_disable();

  // choose a sleep mode
  set_sleep_mode(SLEEP_MODE_IDLE);
  sleep_enable(); // enables the sleep bit in the mcucr register so sleep is possible. just a safety pin

  // initialize timer1
  noInterrupts();           // disable all interrupts
  TCCR1A = 0;
  TCCR1B = 0;
  TCNT1  = 0;

  OCR1A = 16000000 / 64 / SAMPLE_FREQUENCY; // compare match register 16MHz/64/200Hz
  TCCR1B |= (1 << WGM12);   // CTC mode (Clear timer on compare match)
  TCCR1B |= (1 << CS11) | (1 << CS10);  // 64 prescaler
  TIMSK1 |= (1 << OCIE1A);  // enable timer compare interrupt
  interrupts();             // enable all interrupts
}

ISR(TIMER1_COMPA_vect) {        // timer compare interrupt service routine
  power_leds_on();
  if(calibrationMode) {
    if(calibrator.tick()) {
      calibrationMode = false;
      calibrationDone = true;
    }
  } else {
    int change = 0;
    for(int sensor = 0; sensor < settings.s.risingEdgeAmounts_count ; sensor++) {
      change += digitalSensors[sensor].getAmount();
    }
    power_leds_off();
    meter.add(change);

    ticks++;
    if(ticks > TICKS_BETWEEN_SEND) {
      sendValueFlag = true;
      ticks = 0;
    }
  }



}

void loop() {
  if(sendValueFlag) {
    uint64_t currentValue;
    // protected access to variables shared with ISR BEGIN
    noInterrupts();
    sendValueFlag = 0;
    currentValue = meter.getCurrentValue();
    interrupts();
    // protected access to variables shared with ISR END

    if(true || currentValue != lastSentValue) {
      if(settings.s.communicationChannel == MeterReader_Settings_CommunicationChannel_WIRELESS) {
        radio.powerUp();
        sendCounterUpdateByRadio(radioSender, settings.s.meterId, settings.s.seriesId, currentValue);
        radio.powerDown();
      } else {
        sendCounterUpdate(Serial, settings.s.meterId, settings.s.seriesId, currentValue);
      }
      lastSentValue = currentValue;
    }

    if(calibrationDone) {
      calibrationDone = false;
      noInterrupts();

      for(int i = 0 ; i < settings.s.fallingEdgeAmounts_count; i++) {
        settings.s.fallingEdgeAmounts[i] = digitalSensors[i].getFallingEdgeAmount();
        settings.s.risingEdgeAmounts[i] = digitalSensors[i].getRisingEdgeAmount();
      }

      settings.save();
      interrupts();
      sendSettings(Serial, settings.s);
    }
  }

  if(serialinput.process()) {
    switch(serialinput.message.which_message) {
    case MeterReader_Message_calibrate_tag:
      noInterrupts();
      calibrationMode = true;
      calibrator.start(settings.s.fallingEdgeAmounts_count, 1000, 1);

      interrupts();
      break;
    case MeterReader_Message_settings_tag:
      noInterrupts();
      settings.s = serialinput.message.message.settings;
      interrupts();
      settings.save();
      sendSettings(Serial, settings.s);
      break;
    default:
      // ignore message
      break;
    }
  }

  sleep_mode();     // here the device is actually put to sleep
  // the program continues from here after waking up
  sleep_disable();  // first thing after waking from sleep: disable sleep
}

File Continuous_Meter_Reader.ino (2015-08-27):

//-*-c++-*-
/* Meter reader */

#include "Histogram.h"
#include "Meter.h"
#include "Comparator.h"
#include "CounterUpdate_pb.h"
#include "pb_encode.h"
#include "crc32.h"


#define htonl(x) ( ((x)<<24 & 0xFF000000UL) | \
                   ((x)<< 8 & 0x00FF0000UL) | \
                   ((x)>> 8 & 0x0000FF00UL) | \
                   ((x)>>24 & 0x000000FFUL) )


Comparator comparator;
Meter meter;
Histogram histogram;

#define ADCPIN A0
const int SAMPLE_FREQUENCY = 200; // Hz
const int CALIBRATION_SECONDS = 5;
const int SAMPLE_TIME = 1000 / SAMPLE_FREQUENCY;
const int SAMPLES_TO_CALIBRATE = CALIBRATION_SECONDS*1000/SAMPLE_TIME;
const int TICKS_BETWEEN_SEND = 40; // 0.2 seconds

int calibrationSamples=SAMPLES_TO_CALIBRATE;
int calibrationMode;
int sendValueFlag;
unsigned int ticks; // must be big enough to hold TICKS_BETWEEN_SEND

int32_t meterId = 1;
int32_t seriesId = 1;

void setup() {
  sendValueFlag = 0;
  ticks = 0;
  calibrationMode = 1;

  Serial.begin(9600);
  
  comparator.addUnitIncrementListener(&meter);  

 // initialize timer1 
  noInterrupts();           // disable all interrupts
  TCCR1A = 0;
  TCCR1B = 0;
  TCNT1  = 0;

  OCR1A = 16000000/64/SAMPLE_FREQUENCY;  // compare match register 16MHz/64/200Hz
  TCCR1B |= (1 << WGM12);   // CTC mode (Clear timer on compare match)
  TCCR1B |= (1 << CS11) | (1 << CS10);  // 64 prescaler 
  TIMSK1 |= (1 << OCIE1A);  // enable timer compare interrupt
  interrupts();             // enable all interrupts
}

ISR(TIMER1_COMPA_vect)          // timer compare interrupt service routine
{

  int sensorValue = analogRead(ADCPIN);

  if(calibrationMode) {
    if(calibrationSamples > 0) {
      histogram.sample(sensorValue);
      calibrationSamples--;
    } else if(calibrationSamples == 0) {
      int low = histogram.getPercentile(25);
      int high = histogram.getPercentile(75);
      int hysteresis = (high-low)/2;
      int threshold=(high+low)/2;    
      comparator.setHysteresis(hysteresis);
      comparator.setThreshold(threshold);    
      calibrationMode = 0;
    }
  } else {
    comparator.sample(sensorValue);  

    ticks++;    
    if(ticks > TICKS_BETWEEN_SEND) {
      sendValueFlag = 1;
      ticks = 0;
    }
  }


}

void loop() {
    if(sendValueFlag) {
      uint64_t currentValue;
      // protected access to variables shared with ISR BEGIN
      noInterrupts();
      sendValueFlag = 0;
      currentValue = meter.getCurrentValue();
      interrupts();
      // protected access to variables shared with ISR END

      {
        MeterReader_CounterUpdate mymessage = {meterId, seriesId, currentValue};
        uint8_t buffer[MeterReader_CounterUpdate_size];
        
        pb_ostream_t stream = pb_ostream_from_buffer(buffer, sizeof(buffer));
        pb_encode(&stream, MeterReader_CounterUpdate_fields, &mymessage);
        Serial.write("AA");
        serial_write_uint32(stream.bytes_written); 
        Serial.write(buffer, stream.bytes_written);
        uint32_t crc = crc_array(buffer, stream.bytes_written);
        serial_write_uint32(crc);
      }
    }
}

void serial_write_uint32(uint32_t val) {
  uint8_t bytes[4];
  val = htonl(val); // convert to network byte order
  bytes[0] = (val >> 24) & 0xFF;
  bytes[1] = (val >> 16) & 0xFF;
  bytes[2] = (val >> 8) & 0xFF;
  bytes[3] = val & 0xFF;
  
  Serial.write(bytes, 4);
}

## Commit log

2012-05-06 Basic metering and automatic calibration now works.
2012-06-10 Switch to interrupt driven operation.
    Remove all floating point calculations from Meter class.
2012-06-10 Communication between board and node-js server works now.
    Basic HTML page shows count and allows doing measurements.
2012-06-11 Dynamically set the correct host for socket.io.
2015-08-16 The beginnings of a meter server
    Intended to both receive the meter updates from the meter reader
    devices, store the data in the database, serve the web apps and provide
    a json rest API.
2015-08-16 Simple class for optical sensors
    This is just an API experiment for now.
2015-08-16 Get current meter state from database on server start
2015-08-16 Started a react based current meter display.
2015-08-27 Arduino will now send the updates using protobuf
2015-08-28 Convert to Arduino-Makefile and a layout based on Bare-Arduino-Project
2015-08-28 Receiving protobuf messages from the Arduino over serial port now works
2015-08-28 Arduino stores series and meter id in EPROM. Series id is counted up on every boot.
2015-09-10 Support more than one type of message in the communication
    A top level message now contains one of several submessages.
    The Arduino code now sends through a stream without the use of a buffer.
    Added a config message type which is transmitted when the Arduino code
    starts.
2015-09-20 Adds config tool to configure nodes
    Adds unit tests form settings save and load.
    Adds unit test for C++ communication.
    Adds log message type.
    Both Arduino and go can now send and receive.
2015-09-20 Start calibration mode when requested by the config script.
    Store calibration in EEPROM when it is done.
    Change the serial speed to 57600 baud.
2015-09-26 Fix calibration of analog values
    It which went wrong due to an integer overflow in the calibration
    calculation on the Arduino.
2015-09-26 Add the arduino-mock library
    From https://github.com/ikeyasu/arduino-mock
2015-09-26 Support digital sampling mode
    Allow switching sampling mode from the config tools and setting edge
    amounts.
2015-10-02 Add calibration of digital sensors
2015-10-22 Add radio receiver class that will assemble messages from multiple senders
2015-10-31 Integrates wireless sending into the node.
    Adds RadioStation which will be the base station for the system.
    Moves things around a bit.
2015-11-01 Clean up: remove analog sensor support, run code formatter
2015-11-02 Attempt to get the arduino libraries in a way that is compatible with travis ci
    Conflicts:
    .travis.yml
2015-11-02 Travis: Add arduino to package list and remove manual installation of it
2015-11-05 Fixes compile time warnings on tests
    [OpticalSensorTest.cpp]
2015-11-05 Adds the PCB schematic and layout files
    [optical meter reader.brd, optical meter reader.sch, watermeter.brd]
2015-11-05 Add photo of the PCB
2015-11-06 Add power gating
    This only turns on the LEDs when sampling them. We sample the sensors
    once every 5ms and only turn on the LEDs for 50us each time giving us a
    duty cycle of 1% on the LEDs. This reduces power consumption from 95mA
    to 20mA.
2015-11-06 Power down the radio when it is not used.
    This only saves a small amount of power, about 25uA.
2015-11-06 Power off unneeded peripherals
    Turn off the ADC, TWI and Timer0 since they are not used. This saves
    about 0.9mA.
2015-11-06 Enable sleep mode
    Using the least deep sleep mode, IDLE. The timer interrupt will wake up
    the CPU. This saves about 6 mA so the power consumption is now around
    12mA.
2015-11-07 Implement SampleSender in go instead
    This removes python and the python protobuf plugin as a dependency.
    One less thing to get the right version of.
2015-11-09 Add PDF of the board layout and a description in the README on how to use it to see if the board will fit a water meter
2015-11-09 Fix link to board layout PDF and clarify.
2015-11-10 Add sample output from calibration to the README
2015-11-10 Only insert rows in the database when there is an actual change.
2015-11-14 Update of UI. Update SampleSender.go to enable more meters to be sampled. Good for testing UI. Update MeterServer.go to give a better log message.
2015-11-15 More UI prettyfying Handle button state in main.js so that the graphs can update. Add JSON printout i graph area to show how that works.
    Next step is to use those data for something...
2015-11-20 Change time returned from server to milleseconds. Javascript seems to like that better...
2016-04-29 Add instruction for how to initialize a fresh v2 board.
2016-04-29 Switch to v2 in the Makefile
2016-04-29 Add documentation for PCB version 2
    Add -uncalibrate option to ConfigNode.go to make it easier to configure
    a board to have a full set of sensors.
2016-05-01 add v3 eagle files
    [optical meter reader v3.brd, optical meter reader v3.sch]
2016-05-01 Organize information about the two PCB versions better.

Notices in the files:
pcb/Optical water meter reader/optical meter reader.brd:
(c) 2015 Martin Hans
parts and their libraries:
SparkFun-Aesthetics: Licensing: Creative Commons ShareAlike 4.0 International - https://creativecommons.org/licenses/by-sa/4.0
